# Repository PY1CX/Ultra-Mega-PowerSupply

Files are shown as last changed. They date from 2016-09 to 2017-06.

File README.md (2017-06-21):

# Ultra-Mega-PowerSupply 

This is a Open Source Power Supply.

### Why do we need a Open Source Power Supply?
One night, I was bored in front of my computer debugging a product that I was developing and I fought, why not develop a Open Source Power Supply just for fun?
So I started searching around the internet for a programmed open source Power Supply and didn't find anything (we find but it's more fun to make yourself one nice piece of lab equipment.)

### What is the specs of this Power Supply?	
- 0-30v - 0-3A

### Nice features?
- Programmable Shutdown Current	
- Programmable Voltage and Current Curves

### 3D Preview of the PCB
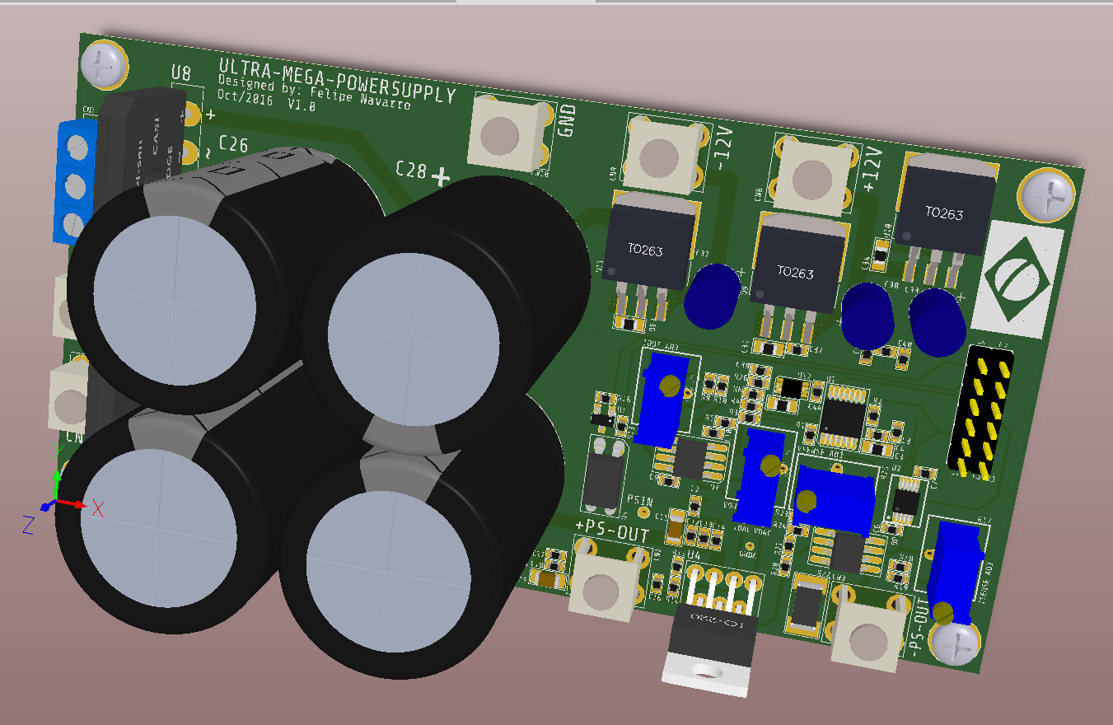
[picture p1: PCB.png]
Preview


Thanks:
Renato Tavares;
Túlio Pires (Need Engenharia);
Alexandre "Pacman" Pereira;
Felipe Neves

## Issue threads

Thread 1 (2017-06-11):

ADC Bug

PY1CX, 2017-06-11:
There is a bug in the ADC on this board. Now correctly feed. You can use any 10 bit ADC with this.

Closed 2017-06-14.

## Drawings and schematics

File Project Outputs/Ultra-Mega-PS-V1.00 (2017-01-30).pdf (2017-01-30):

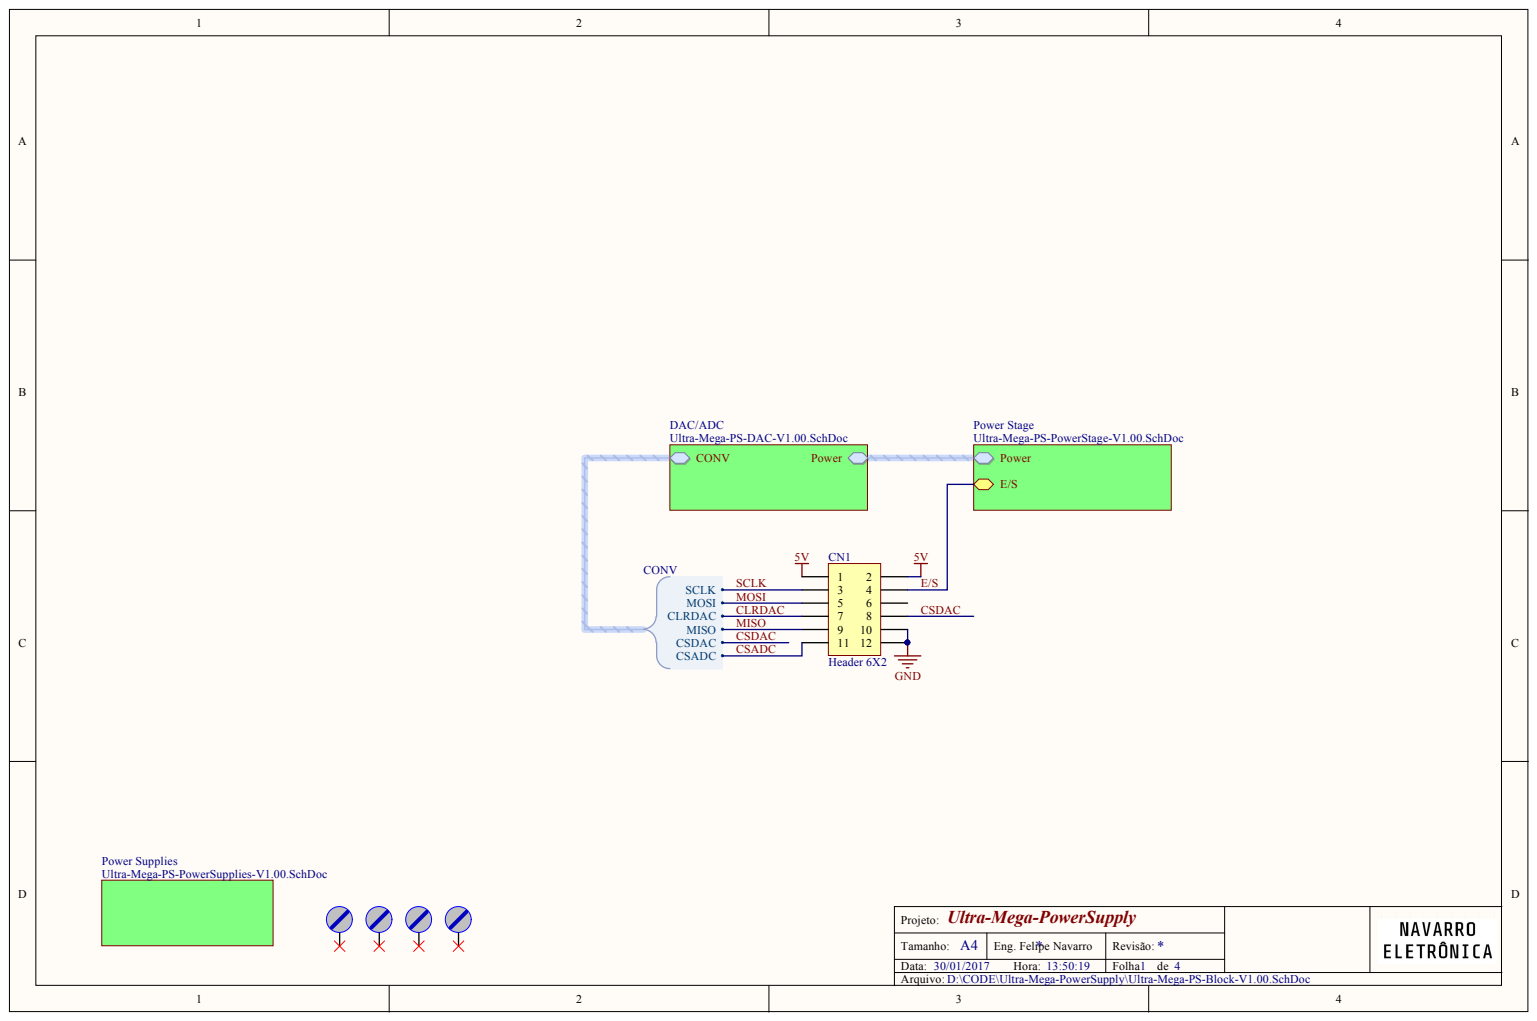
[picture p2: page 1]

DAC/ADC
Ultra-Mega-PS-DAC-V1.00.SchDoc

Power Stage
Ultra-Mega-PS-PowerStage-V1.00.SchDoc
Power

Power Supplies
Ultra-Mega-PS-PowerSupplies-V1.00.SchDoc

Ultra-Mega-PowerSupply Projeto:

Tamanho: A4 | Eng. Felipe Navarro * | Revisão: *

Data: 30/01/2017 Hora: 13:50:19 | | Folha de

D:\CODE\Ultra-Mega-PowerSupply\Ultra-Mega-PS-Block-V1.00.SchDoc

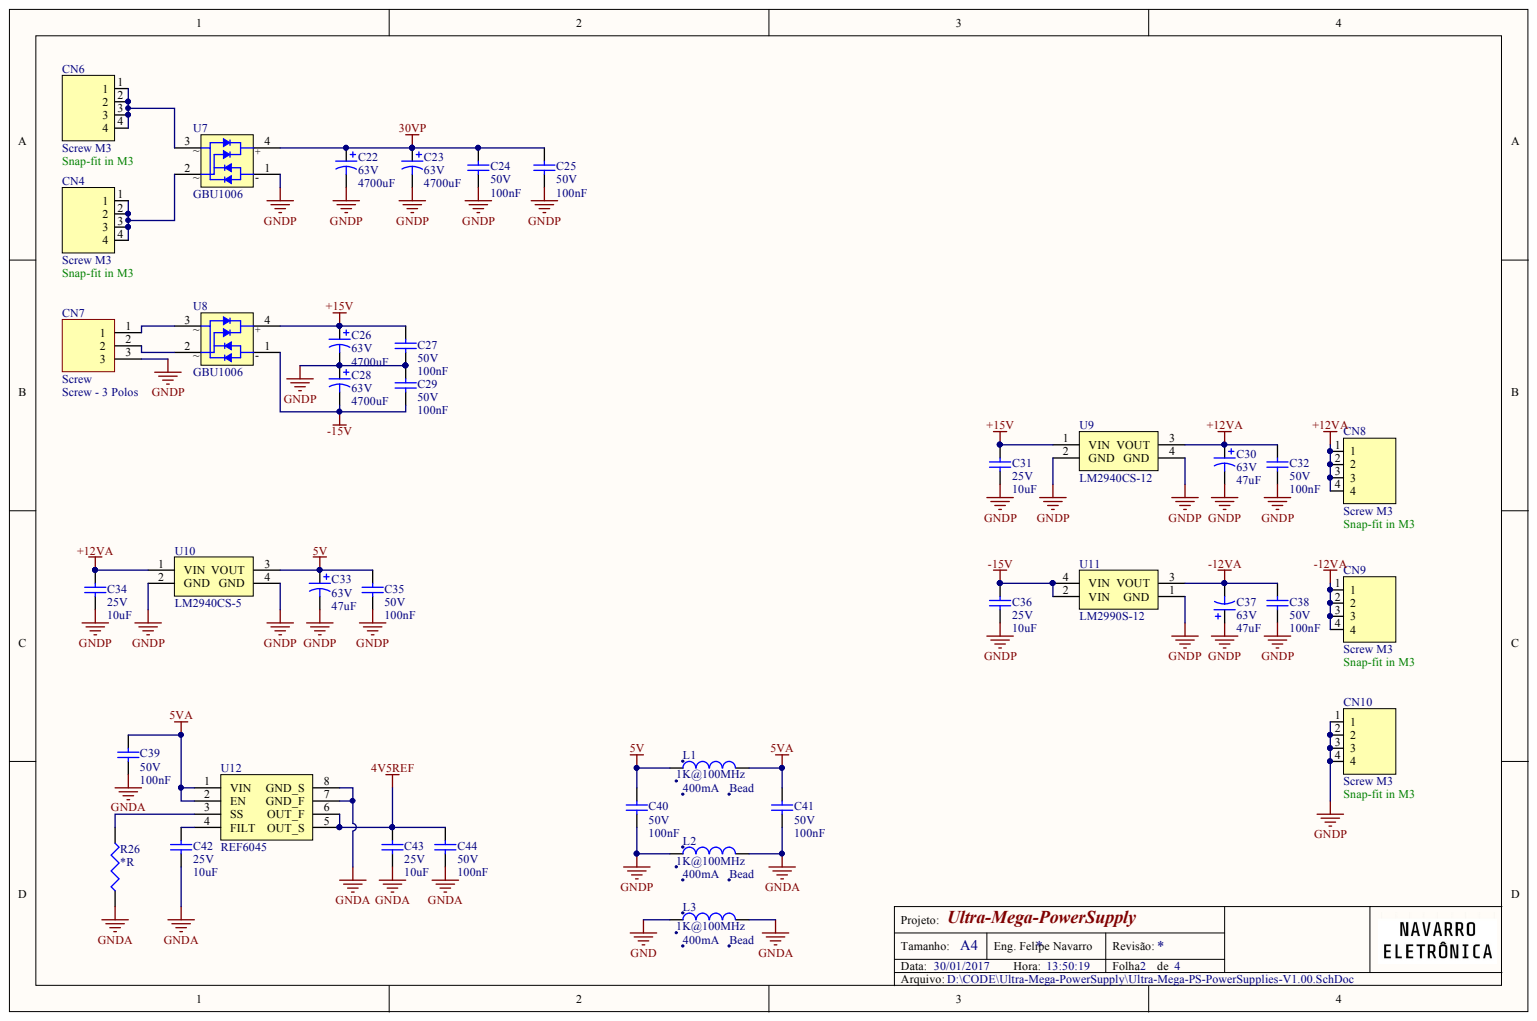
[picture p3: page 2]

Projet o :
Taman h o : A4 | E n g. Fel i pe Navarro | Rev i s ã o : *

/ / H ora: : : | | Fo l h a d e

tra-Mega-PS-Po

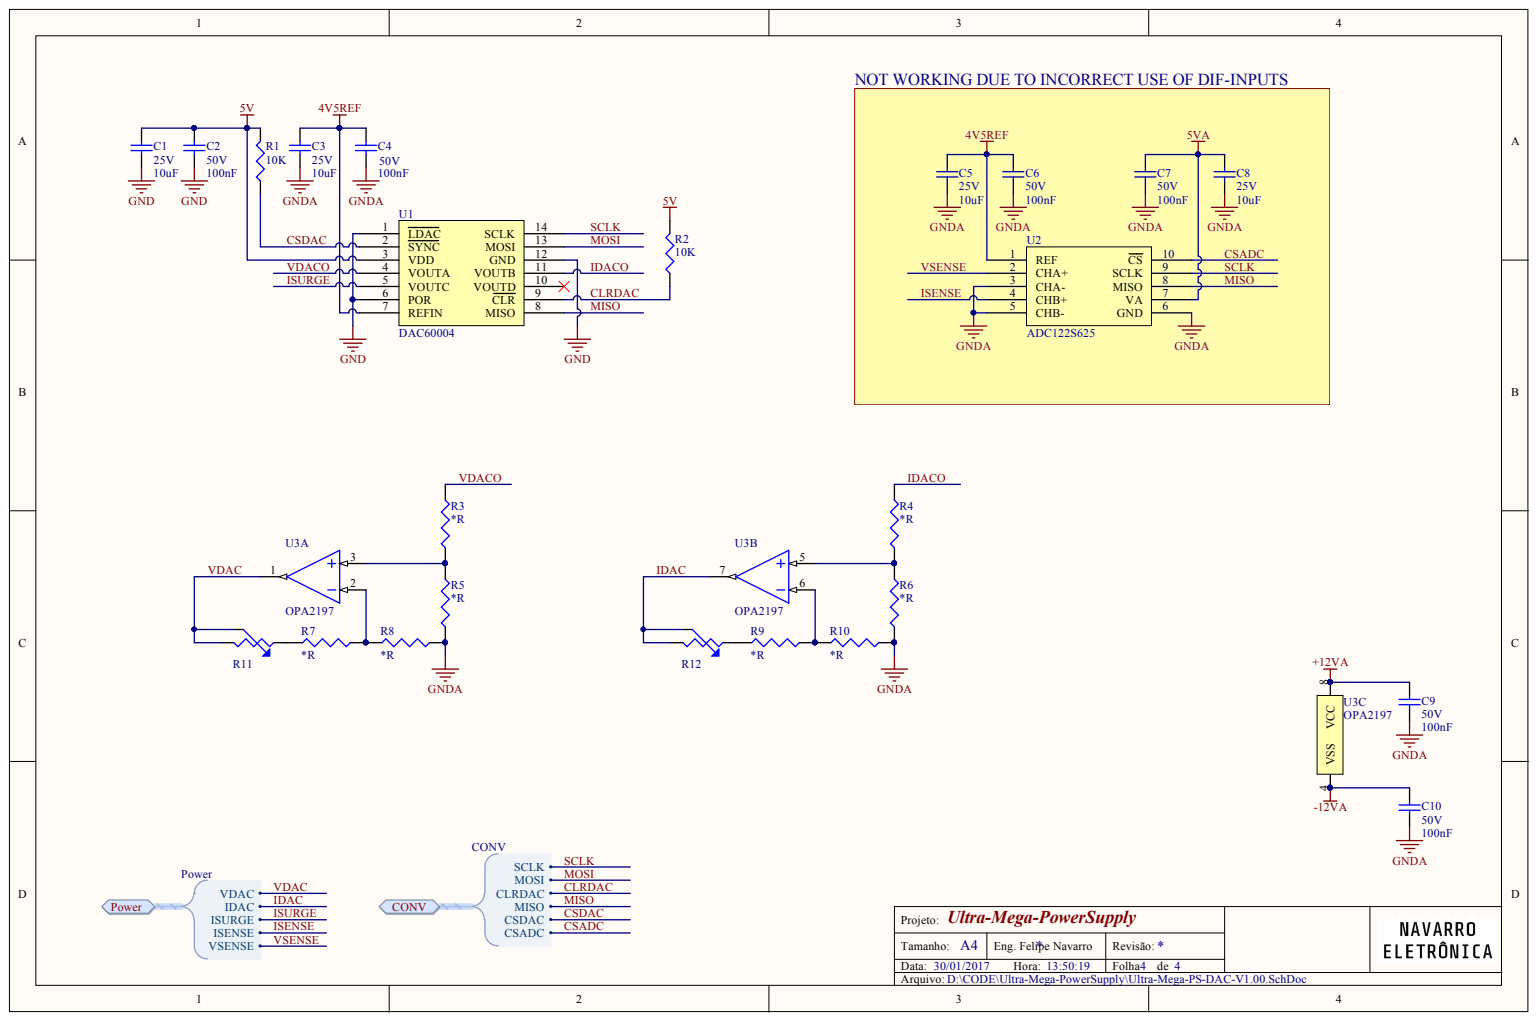
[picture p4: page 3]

NOT WORKING DUE TO INCORRECT USE OF DIF-INPUTS

GNDA CSDAC | | GNDA

SYNC 2 | MOSI

D:\CODE\Ultra-Mega-PowerSupply\Ultra-Mega-PS-DAC-V1.00.SchDoc

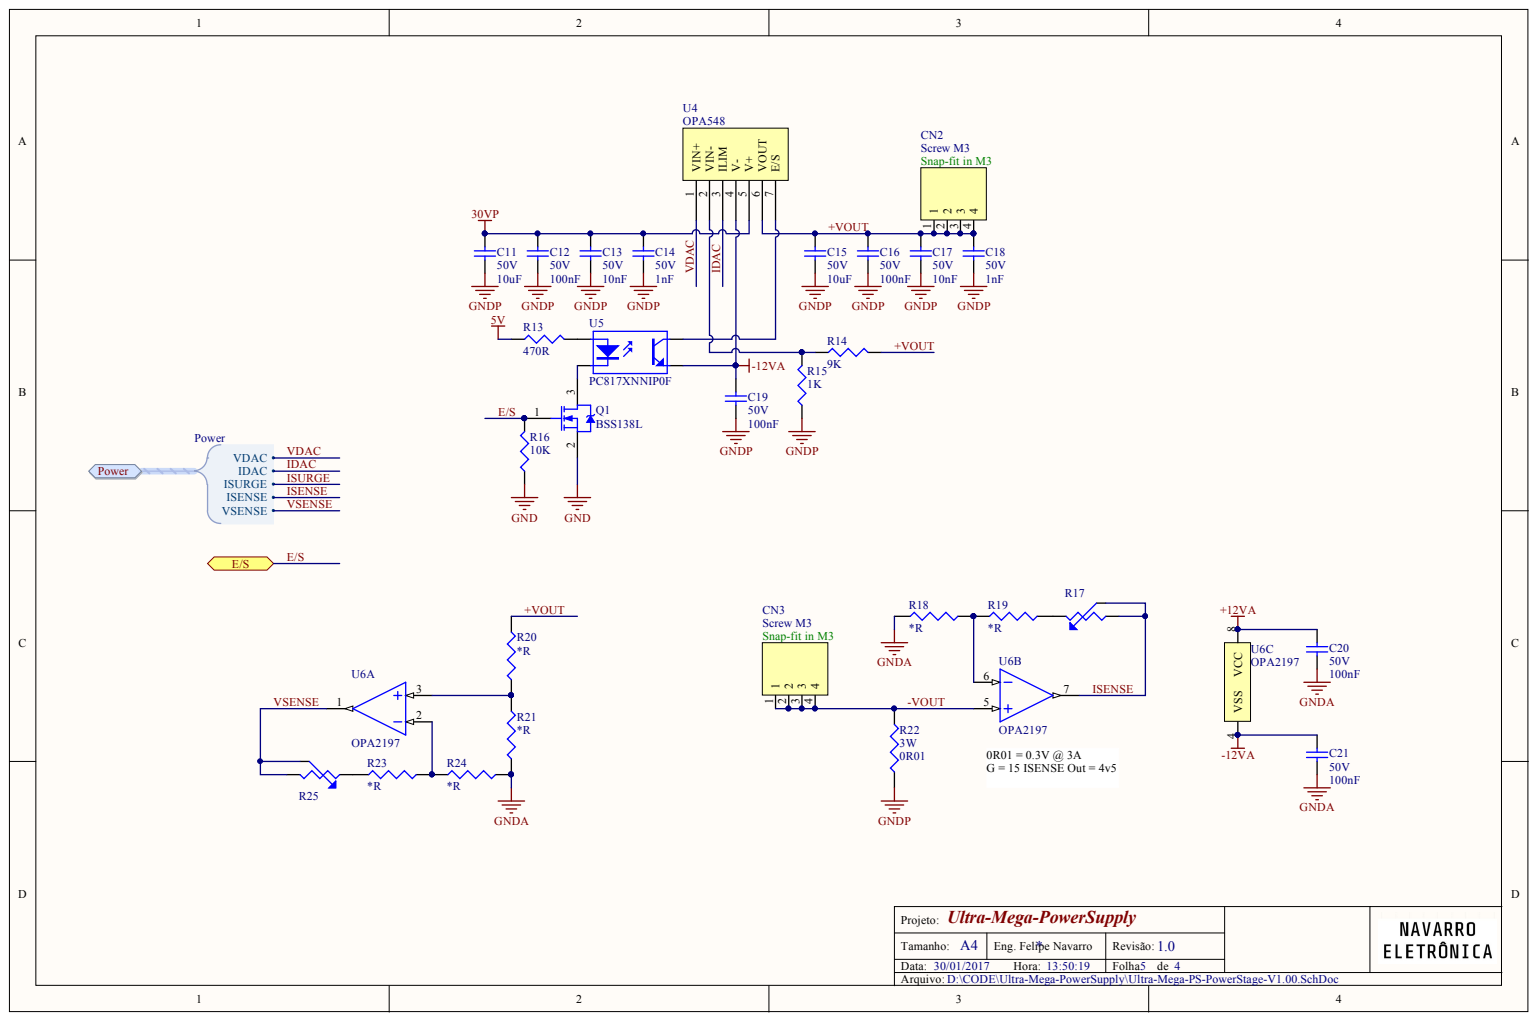
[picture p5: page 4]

Ultra-Mega-PowerSupply Projeto:

Tamanho: A4 | Eng. Felipe Navarro * | Revisão: 1.0

D:\CODE\Ultra-Mega-PowerSupply\Ultra-Mega-PS-PowerStage-V1.00.SchDoc

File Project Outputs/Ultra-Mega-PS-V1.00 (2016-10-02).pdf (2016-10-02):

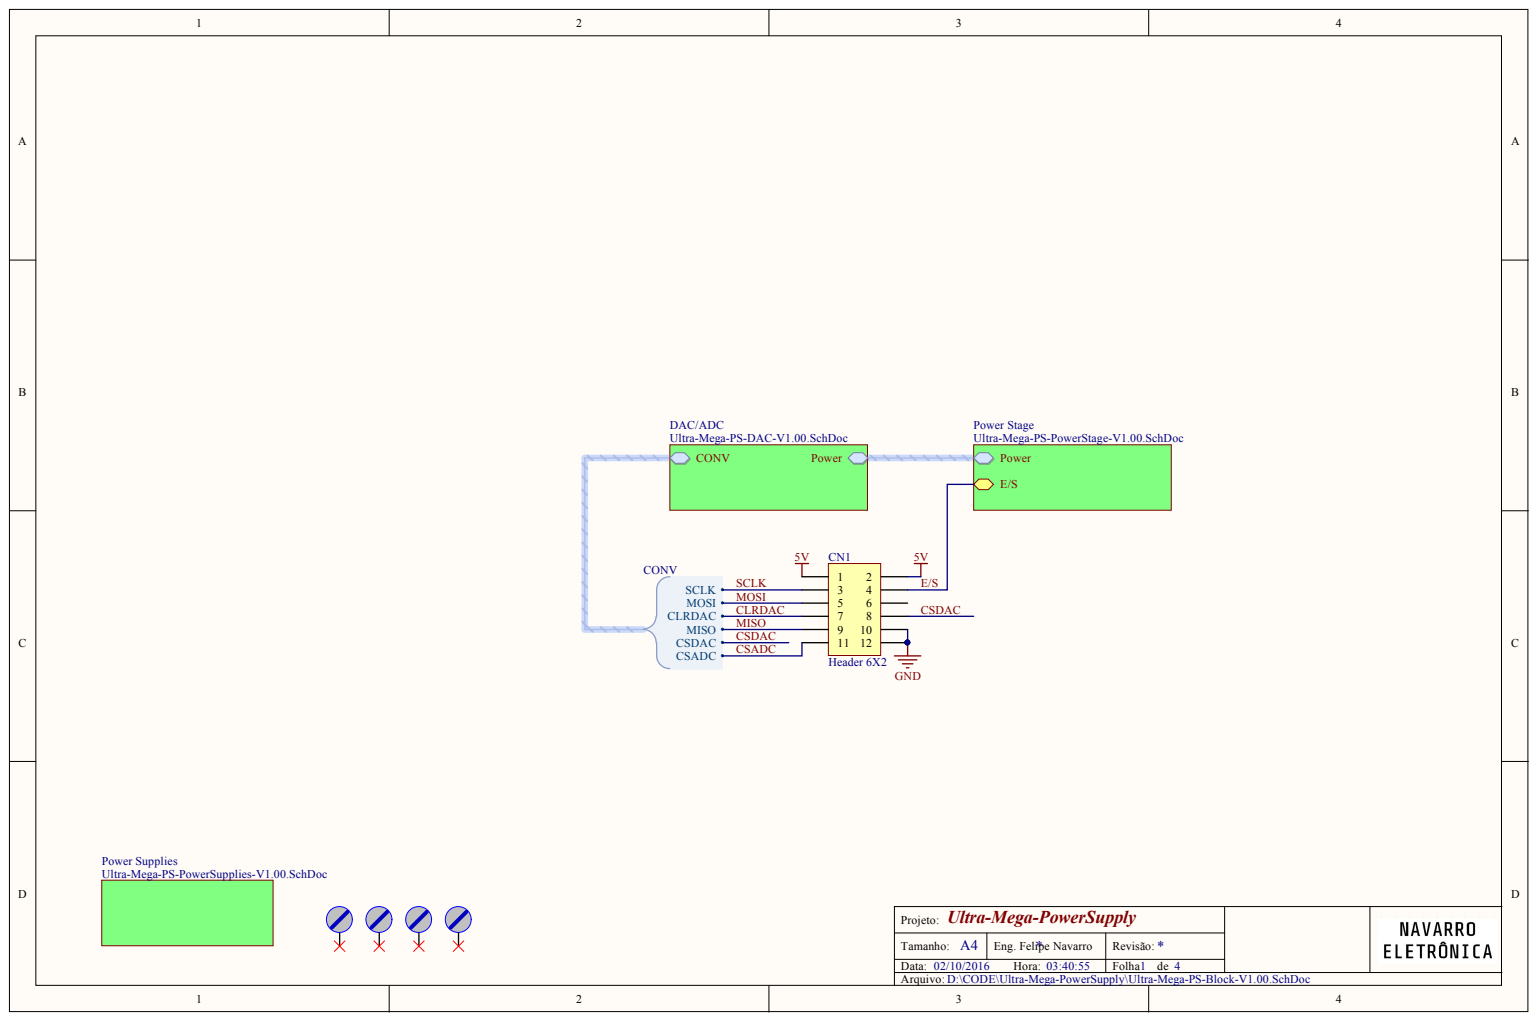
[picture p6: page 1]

DAC/ADC
Ultra-Mega-PS-DAC-V1.00.SchDoc

Power Stage
Ultra-Mega-PS-PowerStage-V1.00.SchDoc
Power

Power Supplies
Ultra-Mega-PS-PowerSupplies-V1.00.SchDoc

Ultra-Mega-PowerSupply Projeto:

Tamanho: A4 | Eng. Felipe Navarro * | Revisão: *

Data: 02/10/2016 Hora: 03:40:55 | | Folha de

D:\CODE\Ultra-Mega-PowerSupply\Ultra-Mega-PS-Block-V1.00.SchDoc

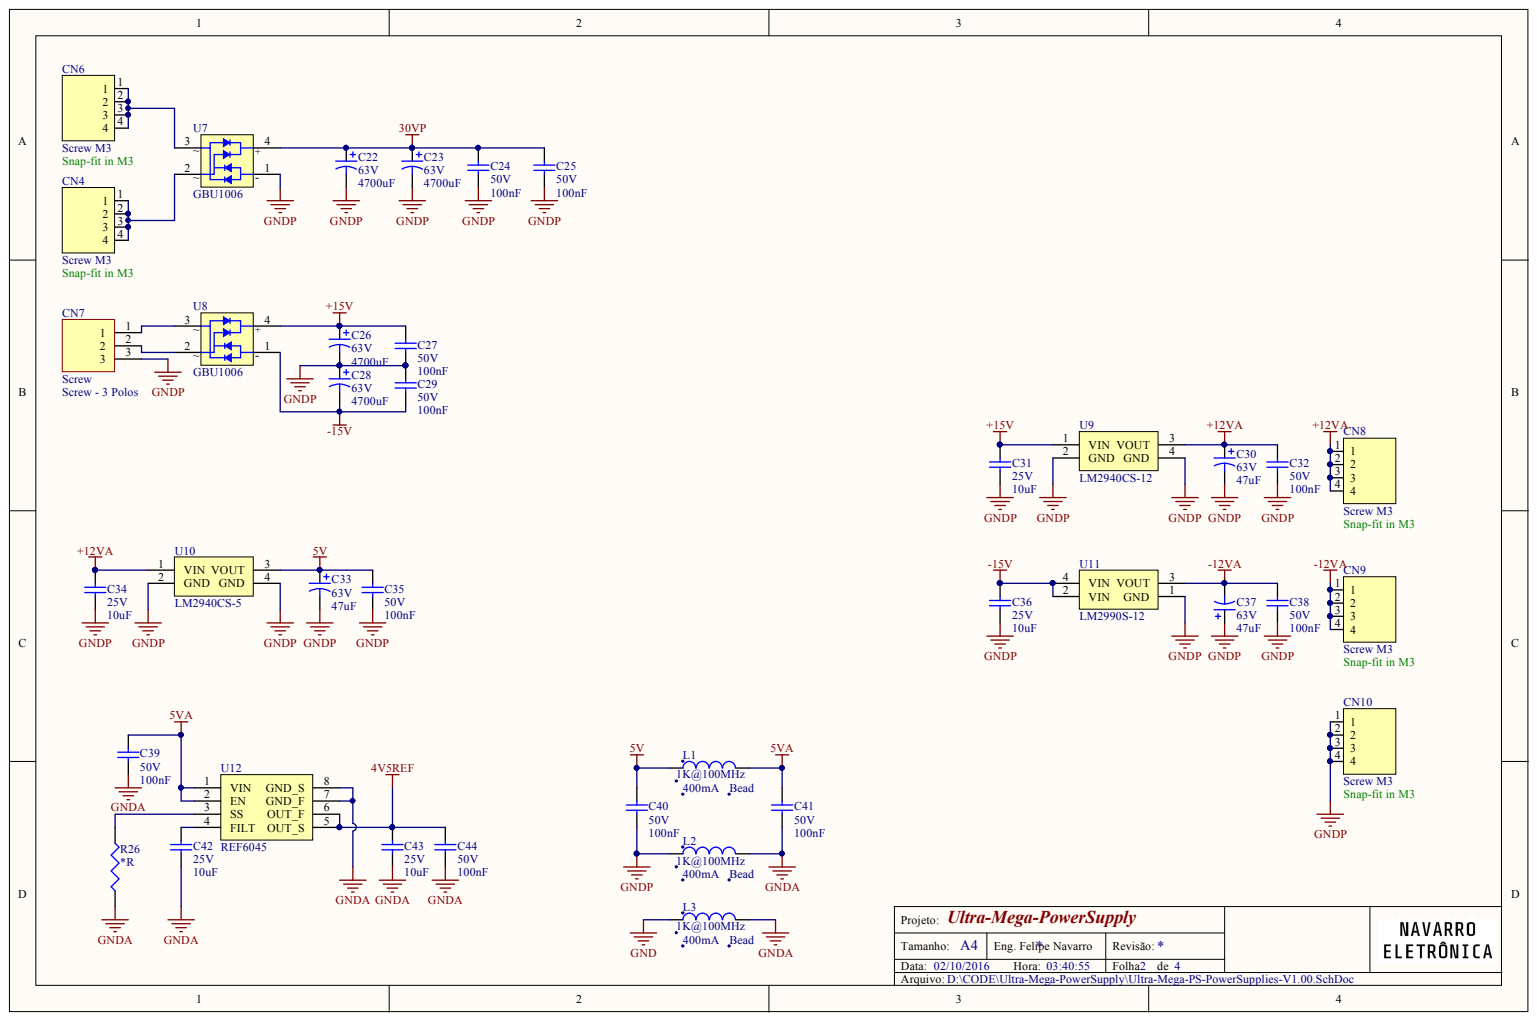
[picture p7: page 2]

Projet o :
Taman h o : A4 | E n g. Fel i pe Navarro | Rev i s ã o : *

/ / H ora: : : | | Fo l h a d e

tra-Mega-PS-Po

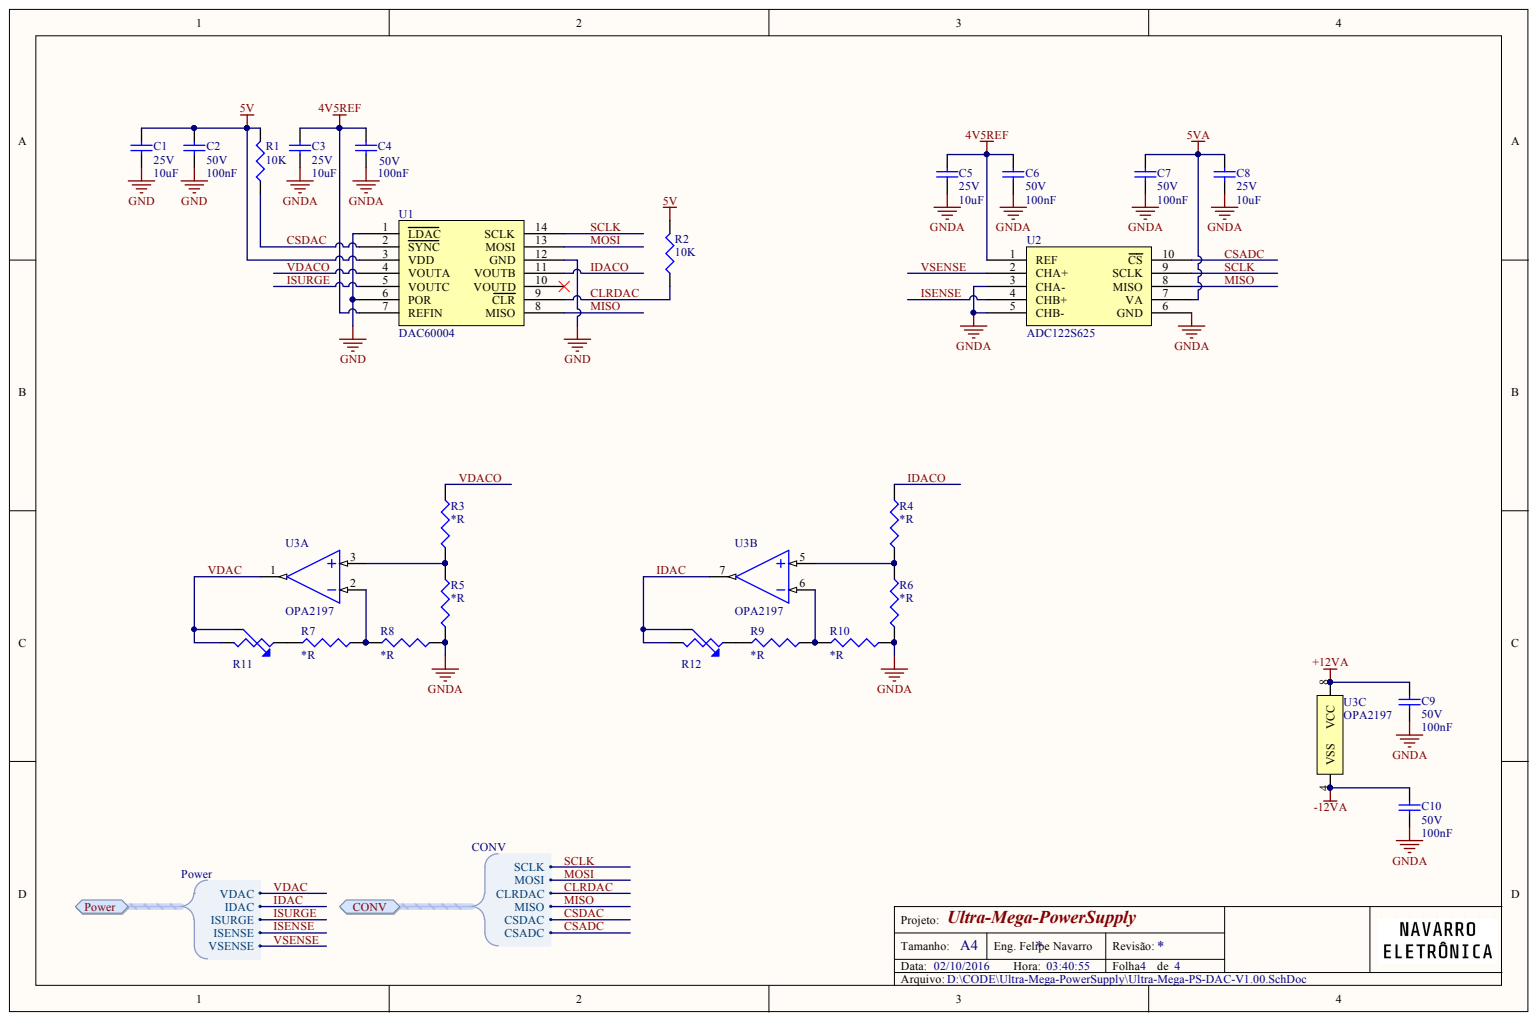
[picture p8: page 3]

D:\CODE\Ultra-Mega-PowerSupply\Ultra-Mega-PS-DAC-V1.00.SchDoc

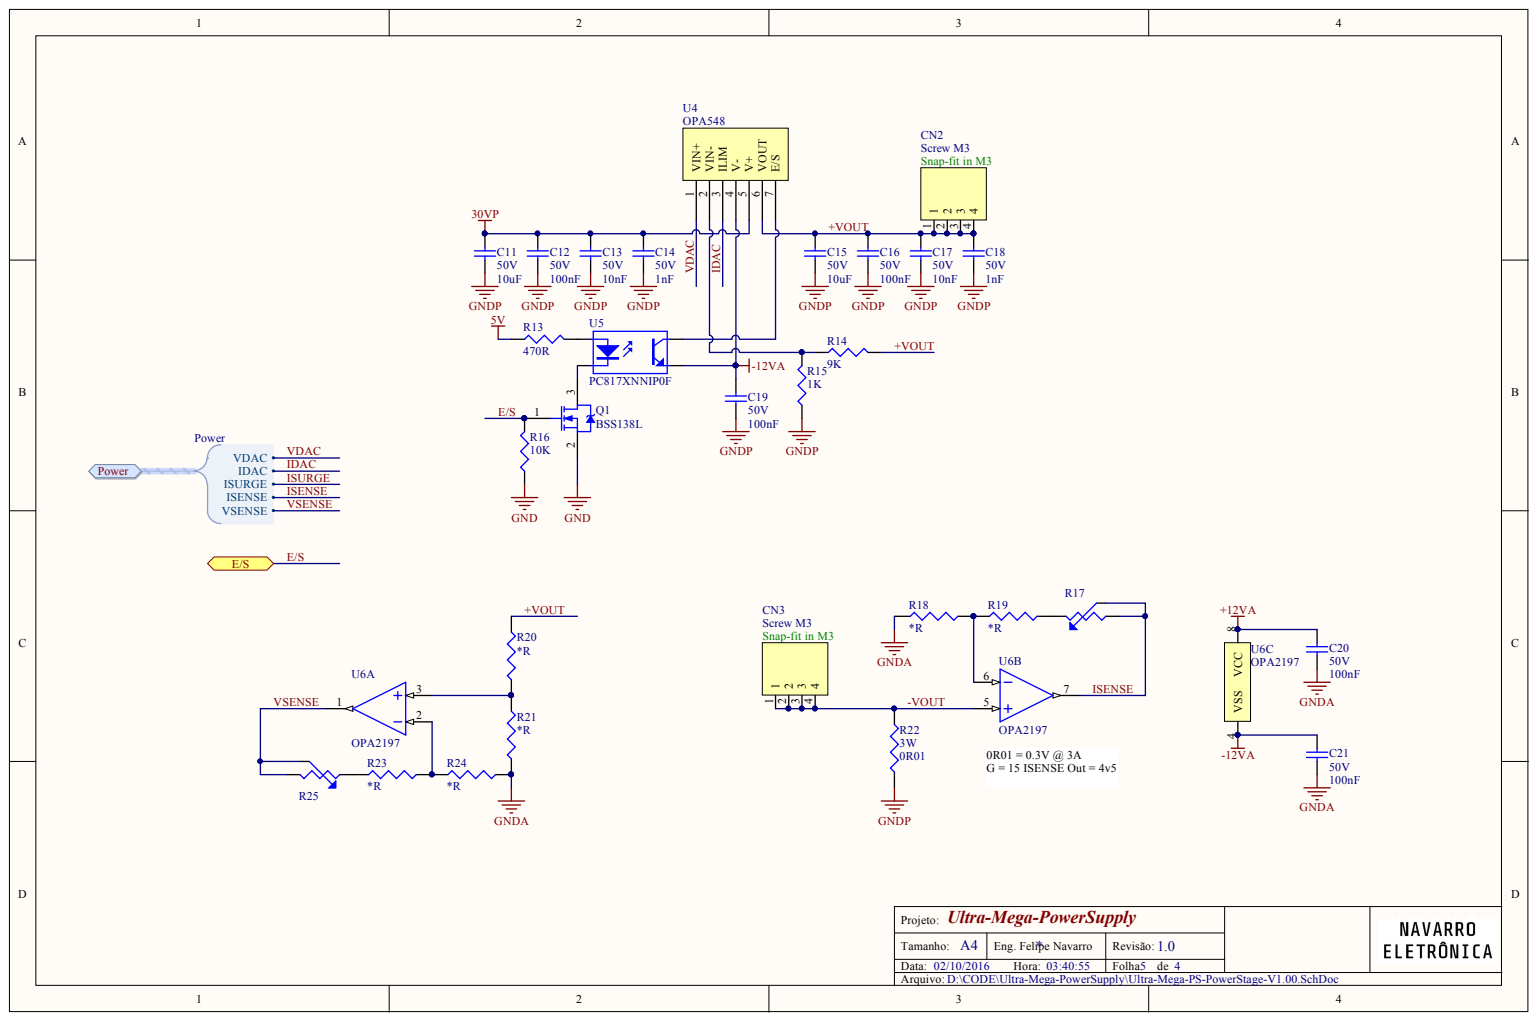
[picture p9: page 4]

Ultra-Mega-PowerSupply Projeto:

Tamanho: A4 | Eng. Felipe Navarro * | Revisão: 1.0

D:\CODE\Ultra-Mega-PowerSupply\Ultra-Mega-PS-PowerStage-V1.00.SchDoc

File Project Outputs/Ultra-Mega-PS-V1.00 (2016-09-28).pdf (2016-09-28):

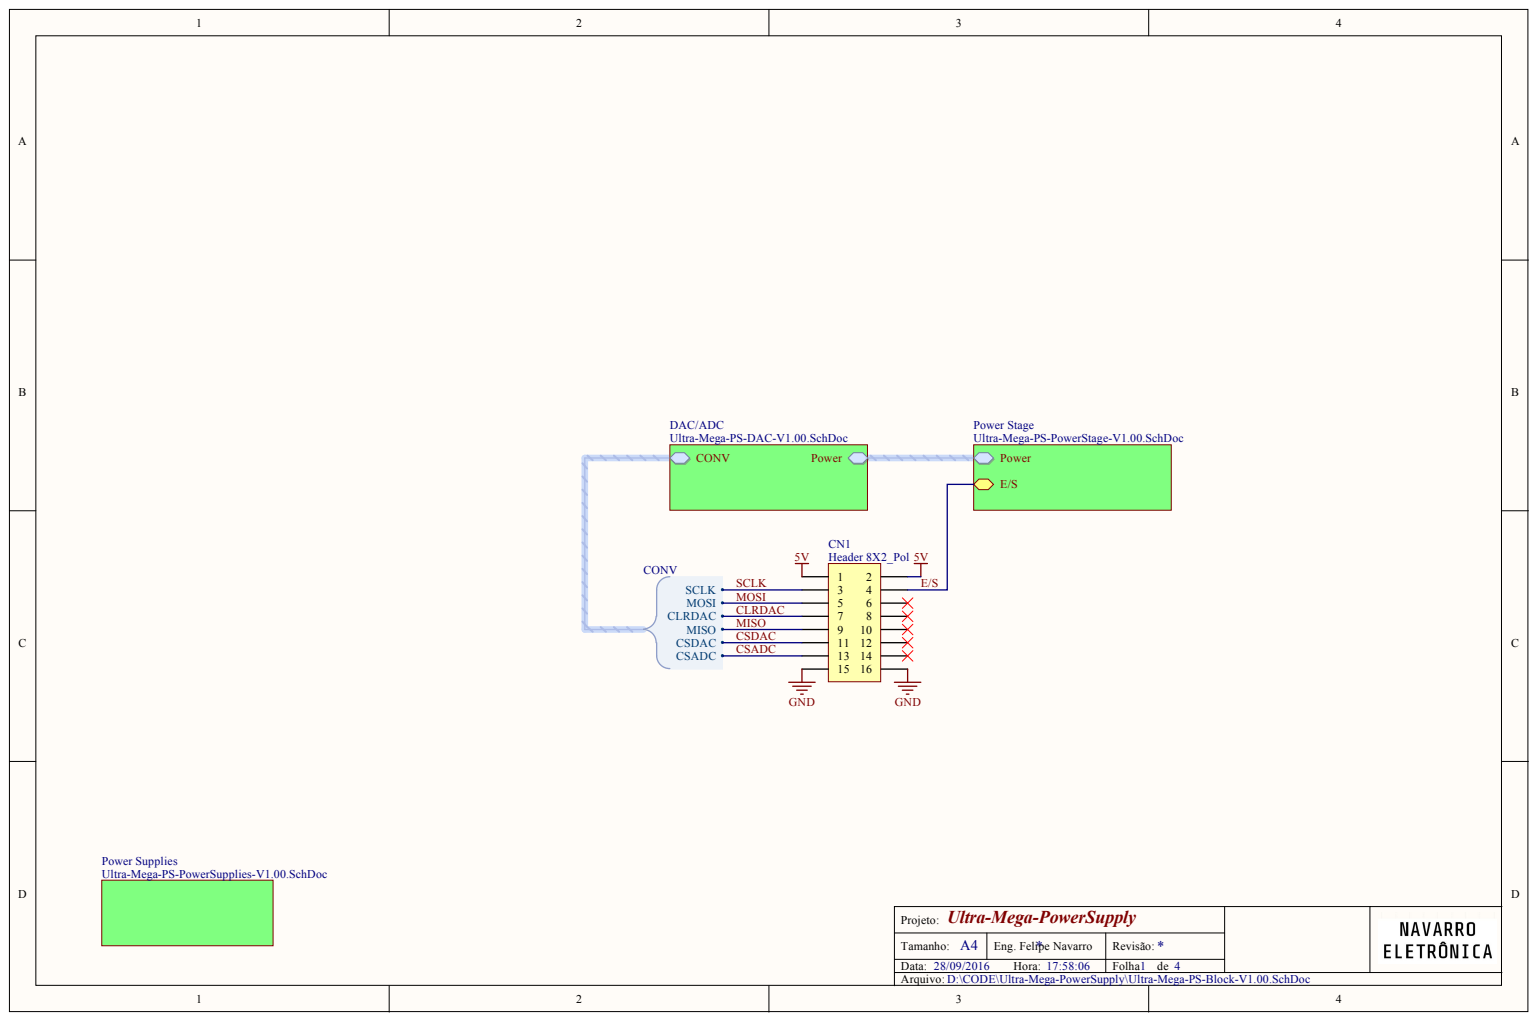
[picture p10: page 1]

DAC/ADC
Ultra-Mega-PS-DAC-V1.00.SchDoc

Power Stage
Ultra-Mega-PS-PowerStage-V1.00.SchDoc
Power

Power Supplies
Ultra-Mega-PS-PowerSupplies-V1.00.SchDoc

Ultra-Mega-PowerSupply Projeto:

Tamanho: A4 | Eng. Felipe Navarro * | Revisão: *

Data: 28/09/2016 Hora: 17:58:06 | | Folha de

D:\CODE\Ultra-Mega-PowerSupply\Ultra-Mega-PS-Block-V1.00.SchDoc

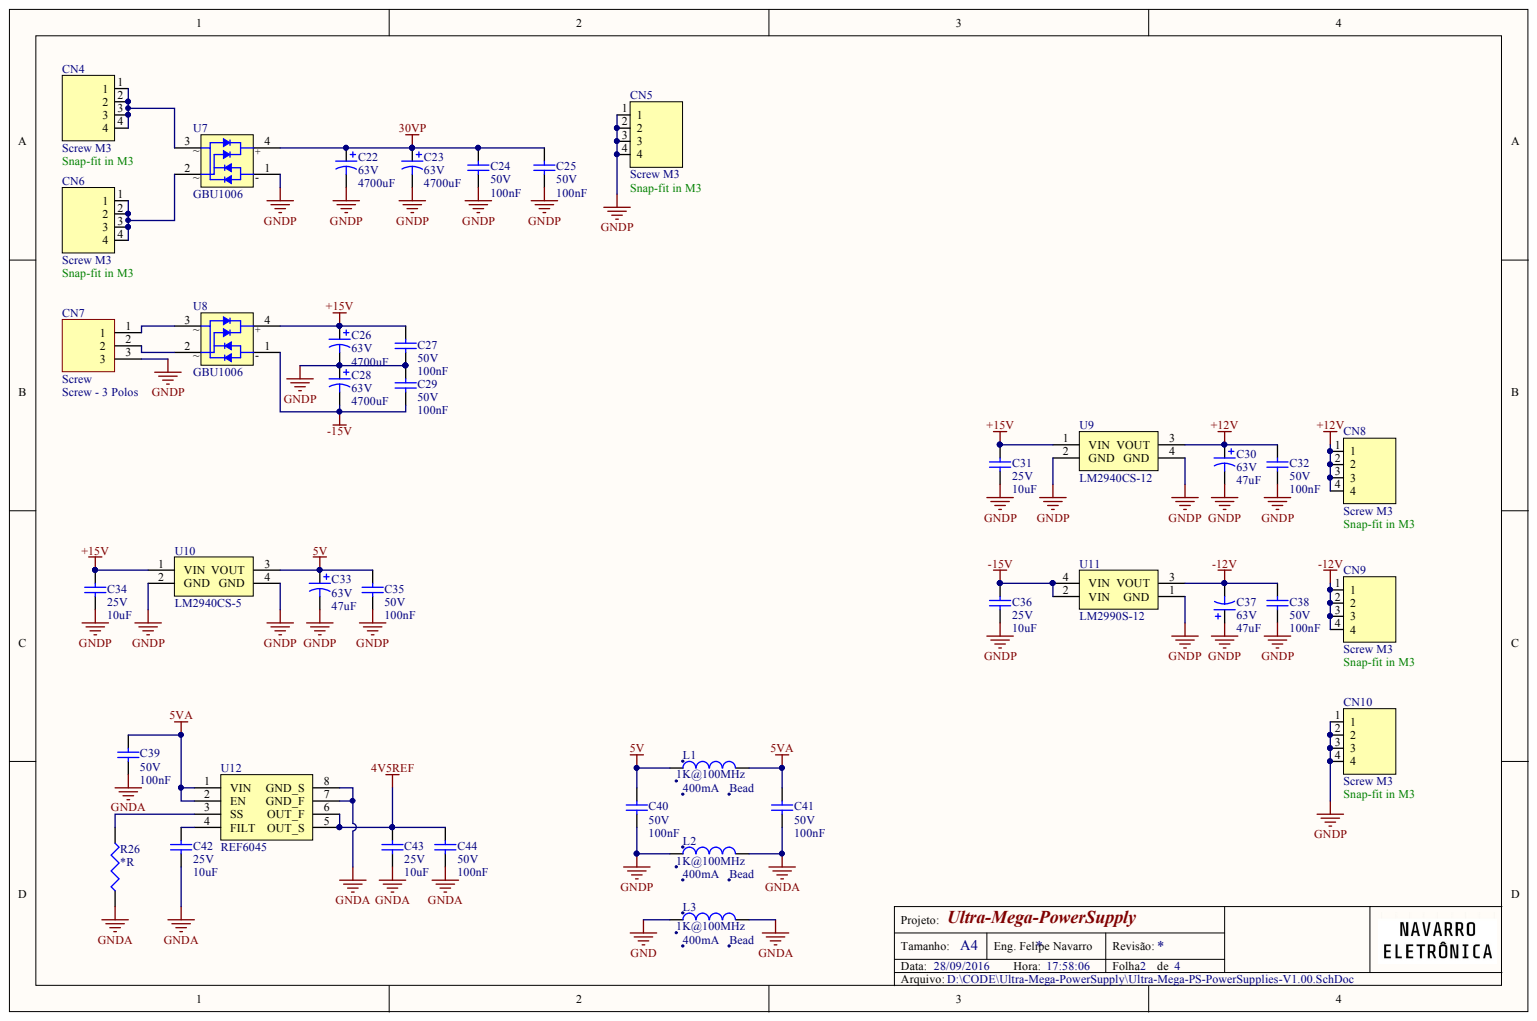
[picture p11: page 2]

Projet o :
Taman h o : A4 | E n g. Fel i pe Navarro | Rev i s ã o : *

/ / H ora: : : | | Fo l h a d e

tra-Mega-PS-Po

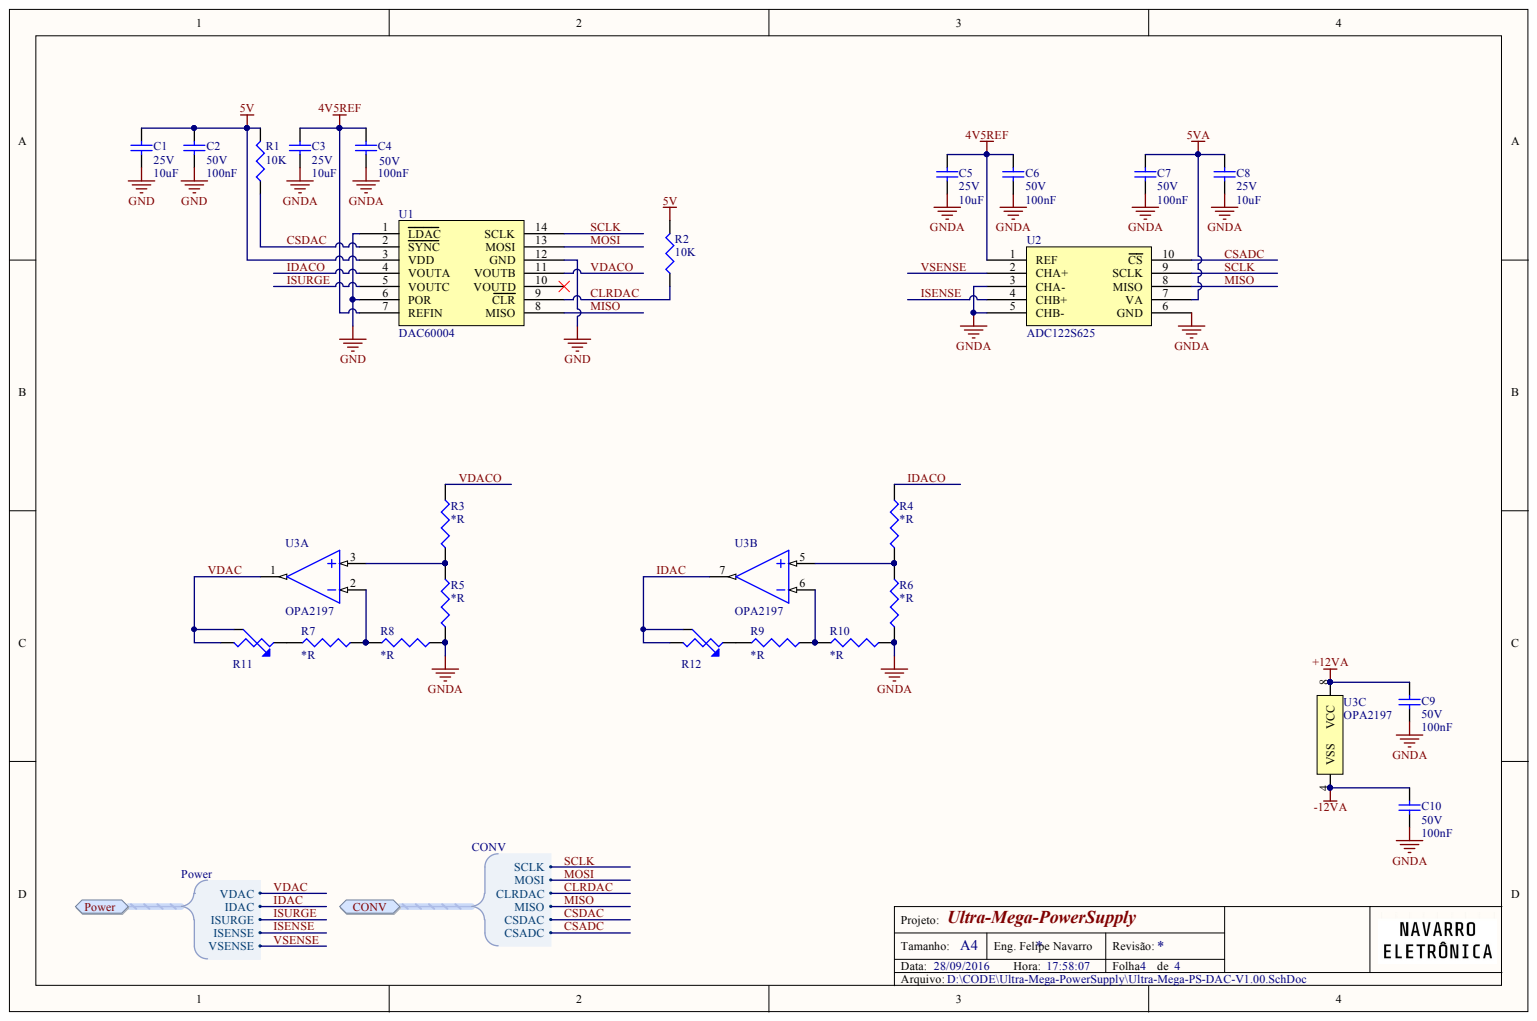
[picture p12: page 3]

D:\CODE\Ultra-Mega-PowerSupply\Ultra-Mega-PS-DAC-V1.00.SchDoc

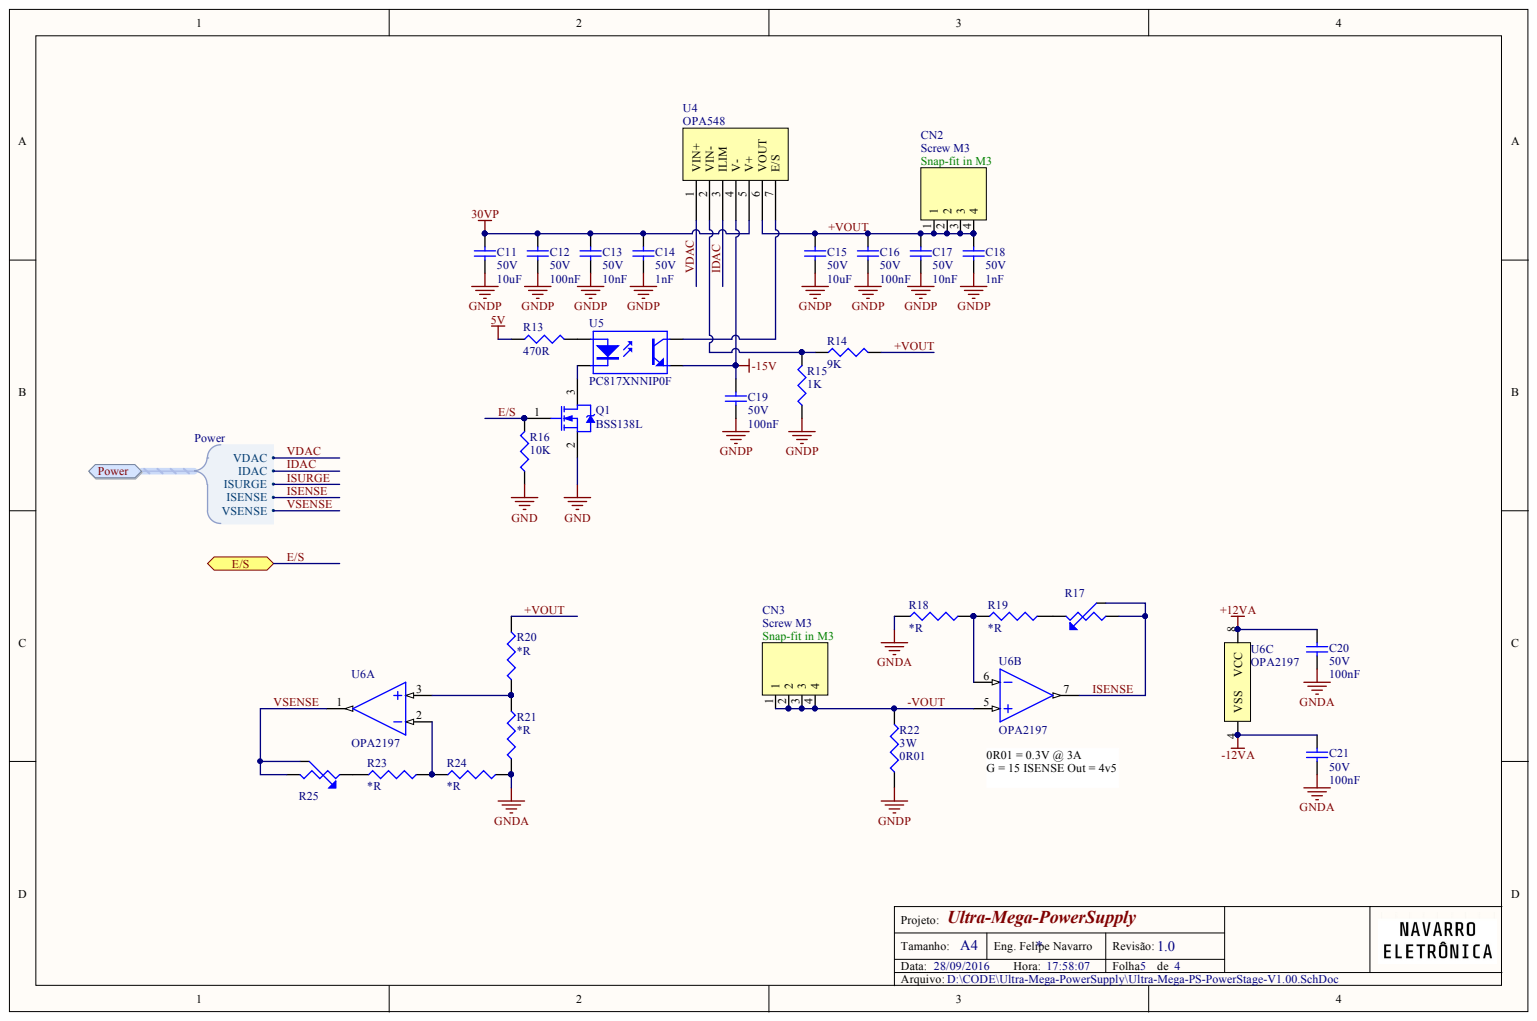
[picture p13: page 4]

Ultra-Mega-PowerSupply Projeto:

Tamanho: A4 | Eng. Felipe Navarro * | Revisão: 1.0

D:\CODE\Ultra-Mega-PowerSupply\Ultra-Mega-PS-PowerStage-V1.00.SchDoc

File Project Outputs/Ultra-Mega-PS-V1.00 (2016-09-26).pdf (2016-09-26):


Arduino
Ultra-Mega-PS-Arduino-V1.00.SchDoc

DAC/ADC
Ultra-Mega-PS-DAC-V1.00.SchDoc

Power Stage
Ultra-Mega-PS-PowerStage-V1.00.SchDoc
Power

Power Supplies
Ultra-Mega-PS-PowerSupplies-V1.00.SchDoc

* Projeto:

Tamanho: A4 | Eng. Felipe Navarro * | Revisão: *

Data: 26/09/2016 Hora: 20:28:18 | | Folha 1 de 5

D:\CODE\Ultra-Mega-PowerSupply\Ultra-Mega-PS-Block-V1.00.SchDoc


RWE 5 V R? 1 K | 5

1 1
1 2
1 3
1 4

* Projet o :

Taman h o : A4 | E n g. Fel i * pe Navarro | Rev i s ã o : *

/ H ora: : | | Fo h a d e

tra-Mega-PS-Ard


* Projet o :

Taman h o : A4 | E n g. Fel i * pe Navarro | Rev i s ã o : *


Ultra-Mega-Power-Supply Projeto:

Tamanho: A4 | Eng. Felipe Navarro * | Revisão: 1.0

Data: 26/09/2016 Hora: 20:28:18 | | Folha 5 de 5

D:\CODE\Ultra-Mega-PowerSupply\Ultra-Mega-PS-PowerStage-V1.00.SchDoc


* Projet o :

Taman h o : A4 | E n g. Fel i * pe Navarro | Rev i s ã o : *

tra-Mega-PS-Po

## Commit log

2016-09-26 Sensing mod
    Changed from INA333 to OPA2197 because it's better for the use. Still
    needs to calculate some resistors values.
    Added trimpots for adjusting the power supply sense.
    [Ultra-Mega-PS-PowerStage-V1.00.SchDoc, Ultra-Mega-PS-PowerSupplies-V1.00.SchDoc]
2016-09-26 Major Changes
    Added -15V supply to OPA548, so we can get 0V. (Still needs to check on
    bench if near 0V the OPA548 will consume any current from this rail);
    Added a PDF with the schematic;
    Added Arduino and Graphical 128x64 LCD
    To be done:
    Bead for +-15V analog power supply
    Check if needs an op-amp after the DAC to drive the OPA548 (maybe we can
    get a little trim?)
    SDCard? Is this necessary? Are someone going to use this? (Maybe add and
    doesn't build it?)
    Output directly to Banana Plugs? Is this ok?
    [Ultra-Mega-PS-Arduino-V1.00.SchDoc, Ultra-Mega-PS-Block-V1.00.SchDoc, Ultra-Mega-PS-DAC-V1.00.SchDoc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]
2016-09-27 Output Disable + DAC ADC Changes
    -Changed the DAC and ADC for a more affordable one. (12bit is ok for
    0-30v 0-3A)
    -Added the Output Disable (still needs to do something with a analog
    comparator for a more reliable and fast disable if something goes wrong
    with your circuit)
    -Big question - To buffer or not to buffer the DAC output? Maybe draw
    and assembly if necessary?
    [Ultra-Mega-PS-Arduino-V1.00.SchDoc, Ultra-Mega-PS-Block-V1.00.SchDoc, Ultra-Mega-PS-DAC-V1.00.SchDoc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]
2016-09-28 Major Changes - Final Schematic before revision
    - Removed the panel from the project. The Arduino and the GLCD will be
    in another PCB for easy routing and possibility to use another
    microcontroler or Another LCD.
    - Added a Op-Amp that can be bypassed in the DAC.
    [Ultra-Mega-PS-Block-V1.00.SchDoc, Ultra-Mega-PS-DAC-V1.00.SchDoc, Ultra-Mega-PS-PowerStage-V1.00.SchDoc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]
2016-10-02 Final PCB and Final SCH
    :)
    [Ultra-Mega-PS-Block-V1.00.SchDoc, Ultra-Mega-PS-DAC-V1.00.SchDoc, Ultra-Mega-PS-PCB.PcbDoc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]
2017-01-30 Schematic Update
    During test we found a bug in the ADC input. The ADC needs half of Vref in negative inputs to work properly. (Page 15 of the datasheet, in bottom: Single-Ended Input Operation )
    To be worked in a next version of the PCB.
2017-02-01 ADC Problem Solved
    Added a simple solution for using the ADC in the next version, a simple 10k divider into the VREF to get 1/2Vref for driving the negative input of the ADC. With this, it's possible to use the ADC122S625 in the next version of the PCB. It's also possible to implement it in Version 1 of the PCB, but I think it's easier and less expensive to just use the ADC input of the microcontroller. It also leads into another problem solution, it's also faster to detect overflow of the current settings. A MUST HAVE to protect expensive components.
    [Ultra-Mega-PS-DAC-V1.00.SchDoc]
2017-06-21 Upload the preview of 3D PCB
